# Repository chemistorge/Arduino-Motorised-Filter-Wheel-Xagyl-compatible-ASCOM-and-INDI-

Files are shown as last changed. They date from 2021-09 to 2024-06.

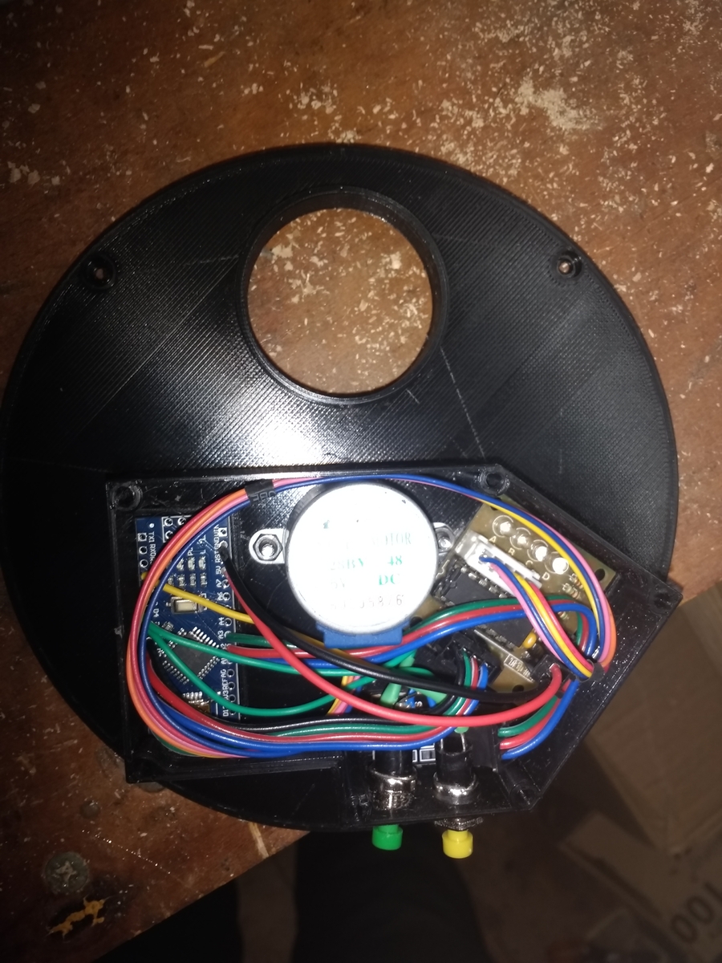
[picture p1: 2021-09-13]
Filter Wheel - Electronics.jpg

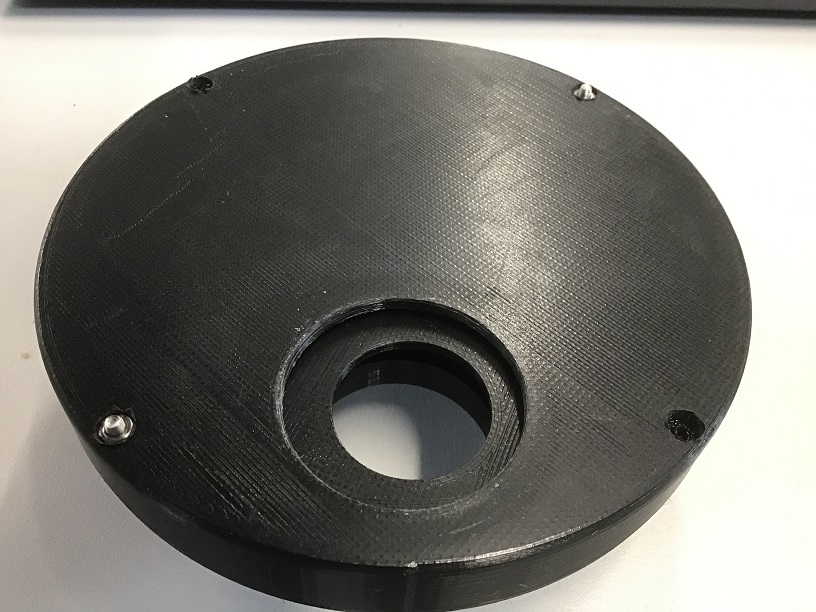
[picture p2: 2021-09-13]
Filter Wheel Back.jpg

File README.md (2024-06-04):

# Arduino-Motorised-Filter-Wheel-Xagyl-compatible-ASCOM-and-INDI-
A 3d printable motorised filter wheel. The wheel is motorised with a 28BYJ-48 stepper with control provided by an Arduino Nano. The firmware is compatible with Xagyl Indi and ASCOM drivers.

I was in the market for a filter wheel, but didn't want to spend the money. I had recently got access to Fusion 360 and fancied desigining my own to print on my Ender 3 V2 printer.

In my research I found this 3D printable model for a filter wheel:https://www.thingiverse.com/thing:1292900

As I have created quite a few arduino projects I also decided to motorise the filter wheel and add capability for interfacing with INDI and ASCOM drivers. After abit of research
I found this GIThub: https://github.com/Blueshawk/Rayz-indi-wheel with an arduino sketch and protocol for the Xagyl brand of filter wheels.

While the existing code sort of worked I found it very buggy and with a high latency for serial commands. Also I could not get it working with ASCOM drivers. 

This GitHub contains the full 3d Printing Files and arduino firmware. The filter wheel is recongnised by both Indi and Ascom, functionally it is limited to changing filters and setting offsets. There is also in the design two buttons that can phyically change filters manually. Also a buzzer or led can be included to have local confirmation of which filter has just been selected.

There are two versions of the filter back plate (M42, and M48) design for either T2 connection or 48 mm common on coma correctors. The filter wheel introduces 21 mm back focus so is designed to replace a ZWO 21 mmm spacer.

The sensor used was an analog Hall Sensor from the 37 in 1 kit of sensors. The magnet used was 12mm x 2mm disc (fits into the raise part of the wheel), but any sized magnet <12 mm OD and <= 2 mm thickness will do. (if you would like help with using a digital Hall Sensor please contact me, the top part of the code has defines that can be changed to select analogue and digital hall sensors.

Main filter box is held together with M3 bolts and nuts (~25 mm). The circuitry lid uses M3 bolts that screw into plastic.

You may need to install the CH340 serial drivers for the arduino nano if using Mac or Windows (Linux supports natively). See here for help: https://learn.sparkfun.com/tutorials/how-to-install-ch340-drivers/all

Link to Discussion on Stargazer Lounge: https://stargazerslounge.com/topic/382864-diy-3d-printable-motorised-125-filter-wheel-ascom-and-indi/

Link to Discussion on Cloudy Nights: https://www.cloudynights.com/topic/788950-3d-printable-motorised-125-filter-wheel-ascom-and-indi-compatible/

Arduino code now updated to allow wheels with any number of filters.

UPDATE:

The homing code file to determining sensor type has been completely rewritten and will now idenitfy if the senor is analog or digital and is active high or low. If analog it will suggest a threshold value. Use this to determine hall sensor type. Ensure that you set the motor steps per revolution before starting. Run the code several time to ensure consistent results, this is prevent false results due to magnet being aligned with sensor on start of run.

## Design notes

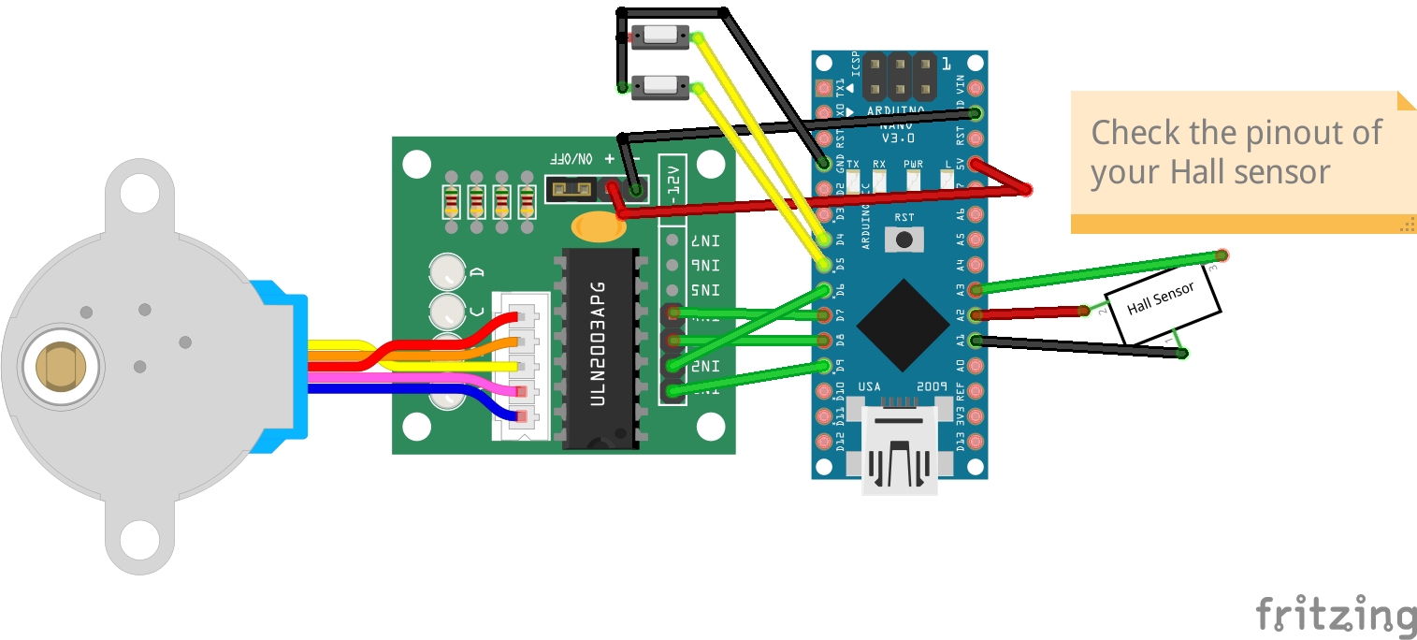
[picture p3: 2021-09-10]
Filter Wheel Schematic.jpg

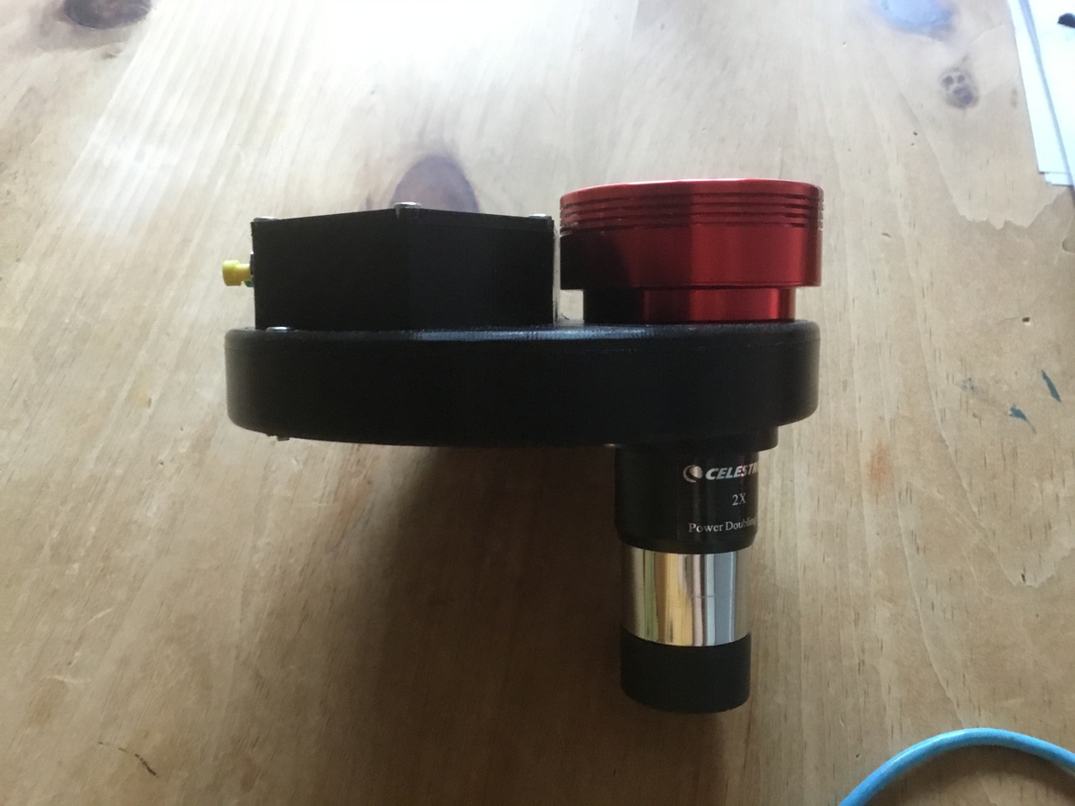
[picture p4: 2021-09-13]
Filter wheel with Camera.jpeg

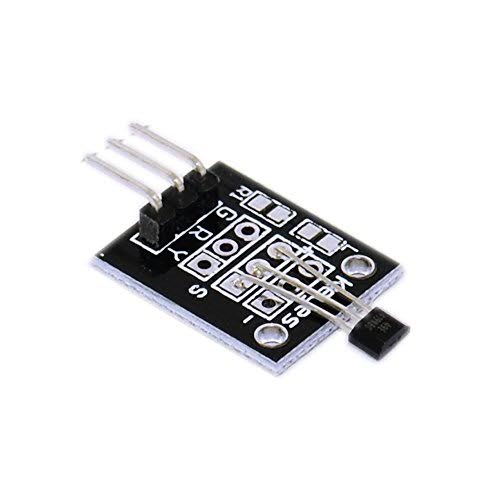
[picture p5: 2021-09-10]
Analog Hall Sensor from 31 sensors in 1 kit .jpg

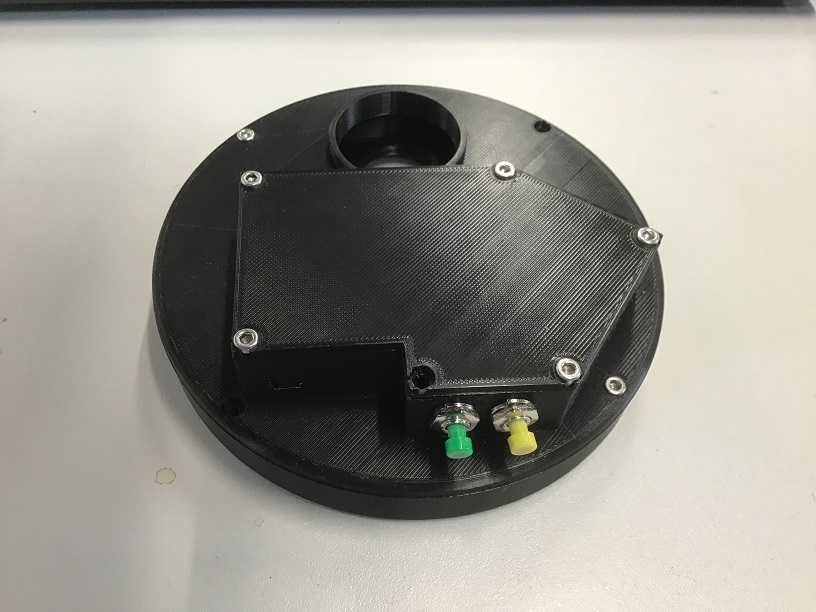
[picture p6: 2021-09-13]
Filter Wheel Top.jpg

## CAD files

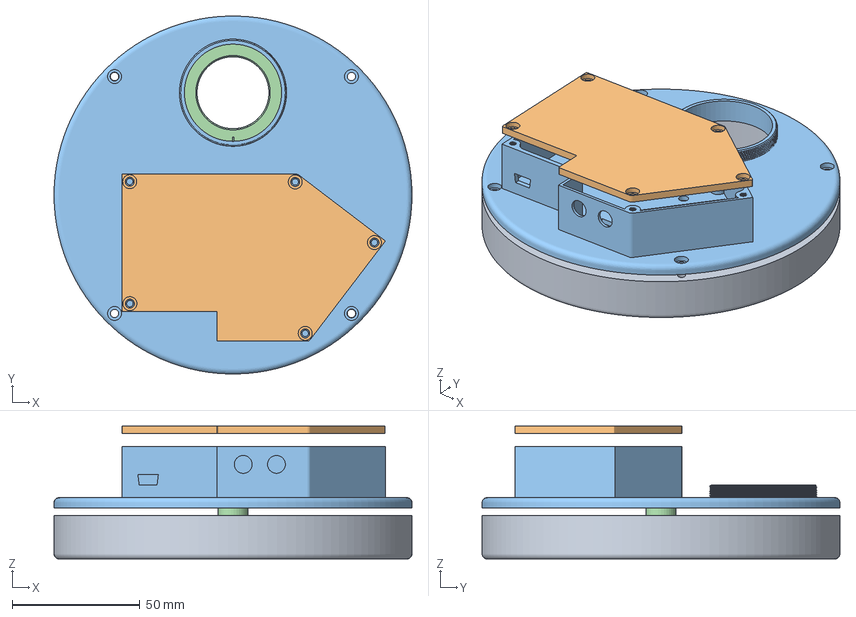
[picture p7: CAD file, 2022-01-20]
3d Print files/Motor Filter Wheel v48.3mf
140.0 x 139.9 x 52.0 mm
Base
Lid
Top
Wheel

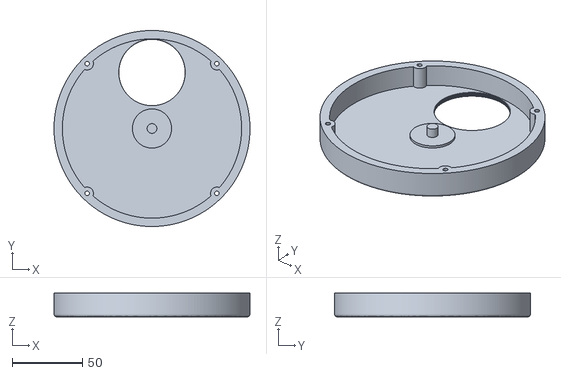
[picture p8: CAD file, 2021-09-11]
3d Print files/Back M48.stl
140.0 x 140.0 x 17.0

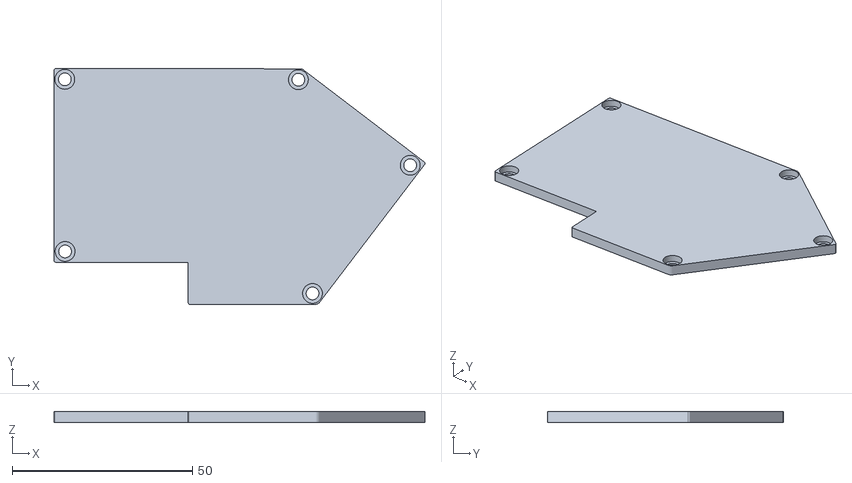
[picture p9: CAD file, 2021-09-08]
3d Print files/Box Lid.stl
102.8 x 65.4 x 3.00

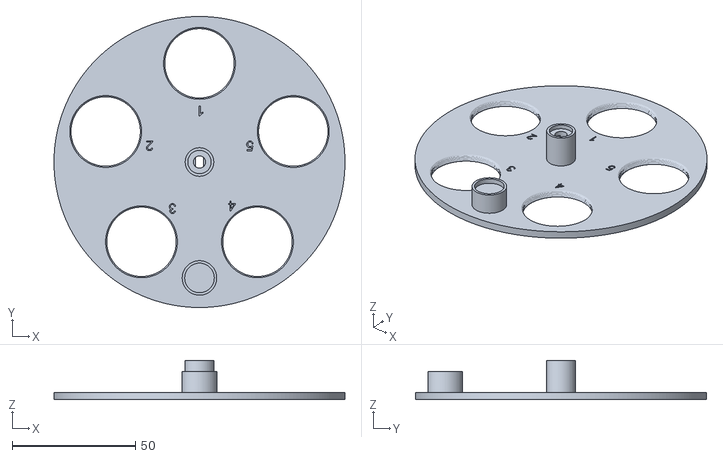
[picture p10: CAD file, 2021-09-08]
3d Print files/Filter Wheel.stl
118.0 x 118.0 x 16.0

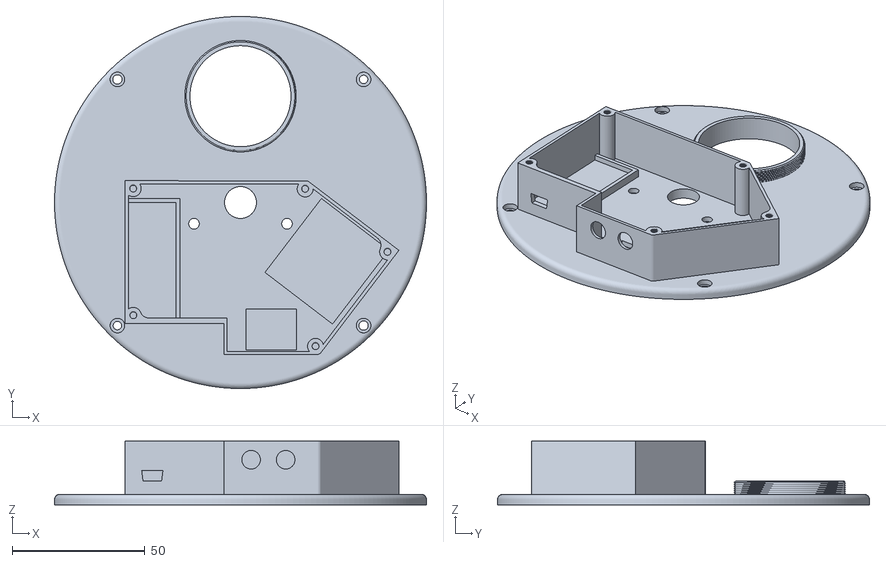
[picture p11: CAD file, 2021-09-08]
3d Print files/Front.stl
140.0 x 140.0 x 24.0

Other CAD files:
3d Print files/Rear 42mm.stl
3d Print files/Motor Filter Wheel 42 mm.f3d
3d Print files/Motor Filter Wheel T48mm v4.f3d

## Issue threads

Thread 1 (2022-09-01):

Support circular positions instead of linear

eavaria, 2022-09-01:
Hello, I just printed your wheel and modified the code a bit so the buttons work every time passing to the next filter instead of having to move linearly between 1 and 5. If you give me access I'll gladly push my branch and open a PR that you can decide to merge or not.

Thanks for your work.

PS: I'm working on adding a small screen, and maybe modifying the design a bit as I've already found some details I'd like to improve

chemistorge, 2022-09-02:
Hi Eavaria,

I have added you

Regards

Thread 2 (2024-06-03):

Doesn't work as it should

jduffas, 2024-06-03:
In fact it does.
Juste a resistor problem.

I would like to delete this comment, but I can't.

jduffas, 2024-06-03:
I understant a little bit more, I added comments in tu program, I see that it thinks all the time it found the magnet...
so, the sensor is a A3144 only.
Do I have to add a 10K resistor?
is it an analog sensor?
if it's digital, is it a high or low?
when setting to High, I fails to home, is all other cases, it says it goes to home, but in fact it doesn't : it detect magnet every time, even when there isn't one.

chemistorge, 2024-06-03:
I have rewrote the home code as it was a complete mess, it will now identify sensor type and if analog the threshold value.

chemistorge, 2024-06-04:
Hi,
You need a 10k resister as a pull up from the signal to 5v for the 3144,
analogue sensors do not. In the absence of a magnetic field an analogue
sensor will read around 512 using analog read where as a digital will be
either 0 or 1023.

Check out my updated homing code to see how I can detect the type of sensor.

Regards

Mark

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

jduffas, 2024-06-04:
Hello,
Thank you for your answer,
I noticed I needed a 10 K resistor.
Now it's working fine, thank you :-)

Closed 2024-06-03.

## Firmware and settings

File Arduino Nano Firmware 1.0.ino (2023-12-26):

#include <AccelStepper.h> //stepper library
#include <EEPROM.h>       //eprom library

// Constants
#define SENSOR A3    // Hall senser pin
#define hallPower A2 // hall 5V pin
#define hallCom A1   // hall GND pin
#define upButton 5    // UpButton Pin
#define downButton 4  // Down BUtton Pin
#define maxSpeed 400  // max motor speed
#define Speed 400     // current speed
#define setAccel 1000 // stepper accelaration
#define buzzerPin 2
#define ledPin 3

// SETTINGS - MAIN PARAMETERS
#define stepsPerRevolution 2048 //set number motor steps for wheel to rotate once
#define numberOfFilters 5
#define offSetResolution 5 //number of motor steps for one offset change
#define homingOffsetSteps 56 // number of steps from homing point to centre of first filter
#define buzzerConnected 0 //1 to enable on pin 2, 0 to disable
#define ledConnected 1 //1 to enable on pin 3, 0 to disable 

// SETTINGS - MOTOR
#define IN1 9 // unipolar motor pins (set all pins)
#define IN2 6 //motor driver step pin
#define IN3 8
#define IN4 7 //motor driver dir pin
#define motorType 1 //1 for unipolar, 2 for motor drive board (e.g. A4988)


// SETTINGS - HALL SENSOR
#define analogSensorThreshold 430 // set the threshold below which the homing sensor is triggered
#define HALLSENSORTYPE 2          // SET to 1 for ANALOG HALL Sensor, CHANGE to 2 for DIGITAL HALL SENSOR
#define HALLACTIVETYPE 2          // SET to 1 for ACTIVE HIGH Digital Sensor, CHANGE to 2 for ACTIVE LOW digital Sensor

#if motorType == 1
  AccelStepper stepper(4, IN1, IN3, IN2, IN4); // Initialise UniPolar Motor
#elif motorType == 2
  AccelStepper stepper(1, IN2, IN4); //Initialise Motor Driver (e.g. A4988)
#endif


const String I_Strings[] = {"Chemistorge_Filter_1.1", "FW3.1.5", "P", "S/N:001", "Max Speed " + String(maxSpeed), "Jitter 1", "PX Offset ", "Theshold 1", "FilterSlots " + String(numberOfFilters), "Pulse Width 4950uS"};

// Variable
int filterPos[numberOfFilters+1]; //Initiaise positions Array
int posOffset[numberOfFilters]; // Initialise Offset Array
bool Error = false;             // homing error flag
int currPos = 0;                // Start at 0
int upButtonState = 1;          // inital state of buttons (Active LOW so set HIGH.
int downButtonState = 1;        // inital state of buttons (Active LOW so set HIGH.

void serialFlush()
{ // functional to flush Serial in buffer if needed.
  if (Serial.available() > 0)
  {
    Serial.read();
  }
}

void writeIntIntoEEPROM(int address, int number)
{ // write one int16 to eprom
  EEPROM.write(address, number >> 8);
  EEPROM.write(address + 1, number & 0xFF);
}
int readIntFromEEPROM(int address)
{ // read int16 from eprom.
  byte byte1 = EEPROM.read(address);
  byte byte2 = EEPROM.read(address + 1);
  return (byte1 << 8) + byte2;
}
void sendSerial(String message)
{ // handle all serial messages to send
  Serial.println(message);
}
void (*resetFunc)(void) = 0; // allow reset of arduino via code

void epromSave(bool showOutput)
{ // Save offset data to eprom, and optionally read back data.
  int Value;
  // EEPROM.write(address, value);
  for (int i = 0; i < numberOfFilters; i++)
  {
    writeIntIntoEEPROM(i * 2 + 50, posOffset[i]);
  }
  if (showOutput)
  {
    for (int i = 0; i < numberOfFilters; i++)
    {
      Value = readIntFromEEPROM(i * 2 + 50);
      sendSerial("P" + String(i + 1) + " Offset " + String(Value));
    }
  }
}

void motor_Off()
{ // power down the stepper to save battery
  digitalWrite(IN1, LOW);
  digitalWrite(IN2, LOW);
  digitalWrite(IN3, LOW);
  digitalWrite(IN4, LOW);
}

#if buzzerConnected == 1
  void playTone(int beeps) 
  { 
    for (int i = 0; i < beeps; i++) 
    { 
      tone(buzzerPin, 1000, 100); 
      delay(200); 
    } 
  }  
#endif

#if ledConnected == 1
  void playLed(int flashes)
  {
    for (int i = 0; i < flashes; i++)
    {
      digitalWrite(ledPin, HIGH);
      delay(300);
      digitalWrite(ledPin, LOW);
      delay(300);
    }
  }
#endif

bool Locate_Home()
{ // locate home
  int HallValue;
  stepper.runToNewPosition(stepper.currentPosition() - 500); // back magnet off sensor
  stepper.moveTo(stepsPerRevolution*1.2);  // set move to as 120% of full revelution so if not homed by then raise error.
  do
  {
    stepper.run(); // run the stepper one step at a time
#if HALLSENSORTYPE == 1
    HallValue = analogRead(SENSOR); // analog sensor
#elif HALLSENSORTYPE == 2
    HallValue = digitalRead(SENSOR); // digital sensor
#endif
    if (stepper.distanceToGo() <= 0)
    { // if we have moved to 3000 then raise error.
      return true;
    }
#if HALLSENSORTYPE == 1
  } while (HallValue > analogSensorThreshold); // analog sensor
#elif HALLSENSORTYPE == 2
  #if HALLACTIVETYPE == 1
    } while (HallValue == LOW); // active HIGH digital sensor
  #elif HALLACTIVETYPE == 2
    } while (HallValue == HIGH); // active LOW digital sensor
  #endif
#endif
  stepper.stop();                // stop stepper as we have homed.
  stepper.setCurrentPosition(0); // set stepper position as 0 (home).
  currPos = 0;                   // set filter position as 0 (i.e homed).
  return false;                  // return with no error.
}

void goToLocation(int newPos)
{ // got to new position.
  if ((newPos < 1) || (newPos > numberOfFilters))
  { // only allow is between 1 and number of filters
    return;
  }
  else if (newPos < currPos)
  { // if new postion is less that current, then home to prevent backlash errors.
    Error = Locate_Home();
  }
  stepper.runToNewPosition(filterPos[newPos] + posOffset[newPos - 1]); // run for from current position to new and include offsets.
  currPos = newPos;
  #if ledConnected == 1                                                   // update position
    playLed(currPos);
  #endif
  #if buzzerConnected == 1
    playTone(currPos);
  #endif
  motor_Off(); // turn off motor coil to save power.
}

void handleSerial(char firstChar, char secondChar)
{                                    // handle valid incoming serial messages.
  int number = int(secondChar - 48); // convert second char to number (ASCI code for 0 is 48 so 48 - 48 is 0, ASCI code for 1 is 49 so 49 - 48 is 1 etc.
  int tmpPoss;                       // hold current position during change.
  switch (toupper(firstChar))
  { // case insensitive //sorts messages by first letter.

  case 'B':            // move back XX places. (ASCOM uses this command for position)
    tmpPoss = currPos; // record current position
    for (int i = 0; i < number; i++)
    { // loop and -1 from current position.
      tmpPoss--;
      if (tmpPoss == 0)
      { // if we reach 0 then wrap to max filter number.
        tmpPoss = numberOfFilters;
      }
    }
    goToLocation(tmpPoss);             // update to new postion.
    sendSerial("P" + String(currPos)); // reply to serial with new position.
    break;

  case 'F':            // move forward XX places. (ASCOM uses this command for position)
    tmpPoss = currPos; // record current position
    for (int i = 0; i < number; i++)
    { // loop and +1 from current position.
      tmpPoss++;
      if (tmpPoss == numberOfFilters + 1)
      { // if we reach out of range then wrap to 1.
        tmpPoss = 1;
      }
    }
    goToLocation(tmpPoss);             // update to new postion.
    sendSerial("P" + String(currPos)); // reply to serial with new position.
    break;

  case 'G':                            // go to Position XX (INDI uses this command for position)
    goToLocation(number);              // update to new postion.
    sendSerial("P" + String(currPos)); // reply to serial with new position.
    break;

  case 'I': // Information
    if (!(number == 2) && !(number == 6))
    {                                // stock information for all expect I2 and I6
      sendSerial(I_Strings[number]); // reply with stock information from array.
    }
    else if (number == 2)
    { // I2 reply with current position eg. P2
      sendSerial(I_Strings[number] + String(currPos));
    }
    else if (number == 6)
    { // I2 reply with current offset for current position eg. P2 Offset 5
      sendSerial("P" + String(currPos) + " Offset " + String(posOffset[currPos - 1] / 5));
    }
    break;

  case 'M': // return a dummy pulse width value
  case 'N':
    sendSerial(I_Strings[9]); // variable not used so don't change
    break;

  case 'O': // return offset for position XX  eg. (O2) >> P2 Offset 5
    if (number > 0 && number < numberOfFilters+1)
    {
      sendSerial("P" + String(number) + " Offset " + String(posOffset[number - 1] / 5));
    }
    break;

  case 'R':
  { // reset commands.
    switch (number)
    {
    case 0: // R0/R1 reset arduino.
    case 1:
      resetFunc();
      break;

    case 2: // R2 reset all offsets to 0 and save to eprom
      for (int i = 0; i < numberOfFilters; i++)
      {
        posOffset[i] = 0;
      }
      epromSave(false);
      Locate_Home();
      goToLocation(1);
      sendSerial("Calibration Removed");
      break;

    case 3:                   // R3 Send dummy jitter value.
      sendSerial("Jitter 1"); // not used so dummy value
      break;

    case 4:                         // R4 send dummy motor speed
      sendSerial("Max Speed 100%"); // not used so dummy value
      break;

    case 5:                      // R5 send dummy threshold.
      sendSerial("Threshold 1"); // not used so dummy value
      break;

    case 6: // R6 Save offsets to eprom (they are anyway when changed)
      epromSave(false);
      break;
    }
  }

  break;

  case 'S':                   // Send dummy speed
    sendSerial("Speed=100%"); // variable not used so don't change
    break;

  case 'T': // send raw sensor value, not useful but needed for ASCOM driver.
    sendSerial(String(SENSOR));
    break;

  case '<':                       // Send dummy speed
    sendSerial("Backwards 100%"); // variable not used so don't change
    break;

  case '>':                     // Send dummy speed
    sendSerial("Forward 100%"); // variable not used so don't change
    break;

  case '[': // send dummy values
  case ']':
    sendSerial("Jitter 1"); // variable not used so don't change
    break;

  case '(': // (X increase offset for current position by 1 unit (1 unit = X steps)
    tmpPoss = currPos;
    posOffset[tmpPoss - 1] = posOffset[tmpPoss - 1] + offSetResolution;
    Locate_Home();
    goToLocation(tmpPoss);
    epromSave(false);
    sendSerial("P" + String(currPos) + " Offset " + String(posOffset[currPos - 1] / 5));
    break;

  case ')': //(X decrease offset for current position by 1 unit (1 unit = X steps)
    tmpPoss = currPos;
    posOffset[tmpPoss - 1] = posOffset[tmpPoss - 1] - offSetResolution;
    Locate_Home();
    goToLocation(tmpPoss);
    epromSave(false);
    sendSerial("P" + String(currPos) + " Offset " + String(posOffset[currPos - 1] / 5));
    break;

  case '{': // send dummy values.
  case '}':
    sendSerial("Theshold 1"); // variable not used so don't change
    break;

  default: // unknown command handled.
    Serial.println("Command Unknown");
  }
}
void setup()
{                             // runs once.
  Serial.begin(9600);         // start serial
  pinMode(hallCom, OUTPUT);   // hall sensor ground pin as output
  pinMode(hallPower, OUTPUT); // hall sensor 5v pin as output
  pinMode(SENSOR, INPUT);     // hall sensor pin as input
  pinMode(IN1, OUTPUT);       // motor pins as outputs.
  pinMode(IN2, OUTPUT);
  pinMode(IN3, OUTPUT);
  pinMode(IN4, OUTPUT);
  pinMode(upButton, INPUT_PULLUP); // button pins as input with pull up resister (active low).
  pinMode(downButton, INPUT_PULLUP);
  pinMode(buzzerPin, OUTPUT);
  pinMode(ledPin, OUTPUT);
  stepper.setCurrentPosition(0);     // set stepper position = 0
  stepper.setMaxSpeed(maxSpeed);     // set max speer
  stepper.setSpeed(Speed);           // set speed
  stepper.setAcceleration(setAccel); // set acceleration
  digitalWrite(hallCom, LOW);        // power hall sensor.
  digitalWrite(hallPower, HIGH);
  filterPos[0] = 0;
  for (int i = 0; i < numberOfFilters; i++)
  { // setup filter pos and read position off sets from eprom.
    int calcPos = (i*(stepsPerRevolution/numberOfFilters)) + homingOffsetSteps;
    filterPos[i+1] = calcPos;
    //Serial.print("Filter Pos ");
    //Serial.print(i+1);
    //Serial.print(" : Value: ");
    //Serial.println(filterPos[i+1]);
    posOffset[i] = readIntFromEEPROM(i * 2 + 50);
  }
  Error = Locate_Home(); // home
  goToLocation(1);       // goto position 1
}

void loop()
{                                        // runs forever.
  upButtonState = digitalRead(upButton); // read button pins and save state
  downButtonState = digitalRead(downButton);

  if (upButtonState == LOW && currPos < numberOfFilters)
  { // if up button pressed and position is less than number of filters increment position
    goToLocation(currPos + 1);
    sendSerial("P" + String(currPos));
    delay(150); // debounce time
  }
  else if (downButtonState == LOW && currPos > 1)
  { // if down button pressed and position is more than 1 decrement position
    goToLocation(currPos - 1);
    sendSerial("P" + String(currPos));
    delay(150); // debounce time
  }

  if (Serial.available() > 0)
  {               // if at least one byte in serial in buffer.
    char one = 0; // initilse char variable.
    char two = 0;
    delay(10); // Wait long enough time for 2 bytes to enter buffer.
    if (!(Serial.peek() > 32))
    {                // get rid of LF and CR and spaces if present.
      Serial.read(); // read and remove from buffer.
    }
    else if (Serial.available() == 1)
    {                // Get rid of single char instructions.
      Serial.read(); // read and remove from buffer.
    }
    else
    {
      one = Serial.read(); // read first Byte
      two = Serial.read(); // read second Byte
      if (!(isDigit(one)) && isDigit(two))
      {                         // check for valid instruction mask e.g. letter - number)
        handleSerial(one, two); // if valid handle it.
      }
      else
      {
        serialFlush(); // else flush invalid. (fail safe)
      }
    }
  }

  if (Error)
  { // if homing does not work print error.
    Serial.println("Homing Failed");
    Error = false;
  }
}

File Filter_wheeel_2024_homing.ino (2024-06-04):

#include <AccelStepper.h>  //stepper library

// Constants
#define SENSOR A3      // Hall senser pin
#define hallPower A2   // hall 5V pin
#define hallCom A1     // hall GND pin
#define maxSpeed 400   // max motor speed
#define Speed 400      // current speed
#define setAccel 1000  // stepper accelaration


// SETTINGS - MAIN PARAMETERS
#define stepsPerRevolution 2048  //set number motor steps for wheel to rotate once


// SETTINGS - MOTOR
#define IN1 9  // unipolar motor pins (set all pins)
#define IN2 6  //motor driver step pin
#define IN3 8
#define IN4 7        //motor driver dir pin
#define motorType 1  //1 for unipolar, 2 for motor drive board (e.g. A4988)


// SETTINGS - HALL SENSOR



#if motorType == 1
AccelStepper stepper(4, IN1, IN3, IN2, IN4);  // Initialise UniPolar Motor
#elif motorType == 2
AccelStepper stepper(1, IN2, IN4);  //Initialise Motor Driver (e.g. A4988)
#endif



// Variable

bool Error = false;  // homing error flag
bool homingSensorFound = true;
int homingType = 4;
int sensorLimitMaxValue = 512;
int sensorLimitMinValue = 512;
bool runOnce = true;
int analogSensorThreshold = 430;  // set the threshold below which the homing sensor is triggered
bool sensorTypeIsDigtial = true;
bool activeHIGH;



void sendSerial(String message) {  // handle all serial messages to send
  Serial.println(message);
}




void motor_Off() {  // power down the stepper to save battery
  digitalWrite(IN1, LOW);
  digitalWrite(IN2, LOW);
  digitalWrite(IN3, LOW);
  digitalWrite(IN4, LOW);
}



bool Locate_Home() {  // locate home
  int HallValue;
  stepper.runToNewPosition(stepper.currentPosition() - 500);  // back magnet off sensor
  stepper.moveTo(stepsPerRevolution * 1.2);                   // set move to as 120% of full revelution so if not homed by then raise error.
  if (homingType == 0) {                                      //measure analog hall sensor voltage low trigger
    do {
      stepper.run();                      // run the stepper one step at a time
      HallValue = analogRead(SENSOR);     // analog sensor
      if (stepper.distanceToGo() <= 0) {  // if we have moved to 3000 then raise error.
        return true;
      }

    } while (HallValue > analogSensorThreshold);  // analog sensor
  } else if (homingType == 1) {                   //measure analog Hall Sensor voltage high trigger
    do {
      stepper.run();                      // run the stepper one step at a time
      HallValue = analogRead(SENSOR);     // analog sensor
      if (stepper.distanceToGo() <= 0) {  // if we have moved to 3000 then raise error.
        return true;
      }

    } while (HallValue < analogSensorThreshold);  // analog sensor
  } else if (homingType == 2) {                   //measure digital High Trigger
    do {
      stepper.run();                      // run the stepper one step at a time
      HallValue = digitalRead(SENSOR);    // digital sensor
      if (stepper.distanceToGo() <= 0) {  // if we have moved to 3000 then raise error.
        return true;
      }
    } while (HallValue == LOW);  // active HIGH digital sensor
  } else if (homingType == 3) {  //measure digtial LOW Trigger
    do {
      stepper.run();                      // run the stepper one step at a time
      HallValue = digitalRead(SENSOR);    // digital sensor
      if (stepper.distanceToGo() <= 0) {  // if we have moved to 3000 then raise error.
        return true;
      }
    } while (HallValue == HIGH);     // active LOW digital sensor
  } else if (homingType == 4) {      //check is Hall Sensor is active HIGH or LOW
    HallValue = analogRead(SENSOR);  // analog sensor

    if (HallValue > 470 && HallValue < 530) {
      sensorTypeIsDigtial = false;
      Serial.println("sensor analog");
      
    }
    if (sensorTypeIsDigtial) {
      activeHIGH = HallValue < 300 ? true : false;
      Serial.println("sensor digital");
      return true;
    }

    do {
      stepper.run();                   // run the stepper one step at a time
      HallValue = analogRead(SENSOR);  // analog sensor

      if (HallValue > 529 && HallValue > sensorLimitMaxValue) {
        sensorLimitMaxValue = HallValue;
      }

      if (HallValue < 471 && HallValue < sensorLimitMinValue) {
        sensorLimitMinValue = HallValue;
      }

    } while (stepper.distanceToGo() > 0);  // analog sensor
    if (sensorLimitMaxValue > 529) {
      activeHIGH = true;
    } else if (sensorLimitMinValue < 471) {
      activeHIGH = false;
    } else {
      homingSensorFound = false;
    }
  }
  stepper.stop();                 // stop stepper as we have homed.
  stepper.setCurrentPosition(0);  // set stepper position as 0 (home).
                                  // set filter position as 0 (i.e homed).
  return false;                   // return with no error.
}




void setup() {                 // runs once.
  Serial.begin(9600);          // start serial
  pinMode(hallCom, OUTPUT);    // hall sensor ground pin as output
  pinMode(hallPower, OUTPUT);  // hall sensor 5v pin as output
  pinMode(SENSOR, INPUT);      // hall sensor pin as input
  pinMode(IN1, OUTPUT);        // motor pins as outputs.
  pinMode(IN2, OUTPUT);
  pinMode(IN3, OUTPUT);
  pinMode(IN4, OUTPUT);
  stepper.setCurrentPosition(0);      // set stepper position = 0
  stepper.setMaxSpeed(maxSpeed);      // set max speer
  stepper.setSpeed(Speed);            // set speed
  stepper.setAcceleration(setAccel);  // set acceleration
  digitalWrite(hallCom, LOW);         // power hall sensor.
  digitalWrite(hallPower, HIGH);



  //Error = Locate_Home();  // home
}
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

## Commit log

2021-09-10 Rename Motor_Filter.ino to Arduino Nano Firmware 1.0.ino
2022-01-20 Update Arduino Nano Firmware 1.0.ino
    Made it easier to change between analog hall sensor and digital hall sensor, just change define options at top of code.
2022-01-20 Update Arduino Nano Firmware 1.0.ino
2022-08-20 Update Arduino Nano Firmware 1.0.ino
    Added code for buzzer on pin D3 to indicate filter position.
    [Arduino Nano Firmware 1.0.ino]
2023-12-26 Update Arduino Nano Firmware 1.0.ino
    Updated code to allow filter numbers up to 8.
    Also added options to either use unipolar motors or stepper motor driver (e.g. A4988)
2023-12-26 Update Arduino Nano Firmware 1.0.ino
    Added missing pinMode for led pin.
    [Arduino Nano Firmware 1.0.ino]
2023-12-26 Update README.md
    Add note about updated arduino code
2024-01-07 Create Arduino FIrmware_old.ino
    Re-added old firmware
2024-01-08 Add files via upload
    Start of automated homing sensor detect not finished or tested yet.
2024-06-03 Update Filter_wheeel_2024_homing.ino
    Complete rewrite of code due to serious errors
    [Filter_wheeel_2024_homing.ino]
2024-06-04 Update Filter_wheeel_2024_homing.ino
    Edited recording of upper and lower analog sensors values to determine the limits.
